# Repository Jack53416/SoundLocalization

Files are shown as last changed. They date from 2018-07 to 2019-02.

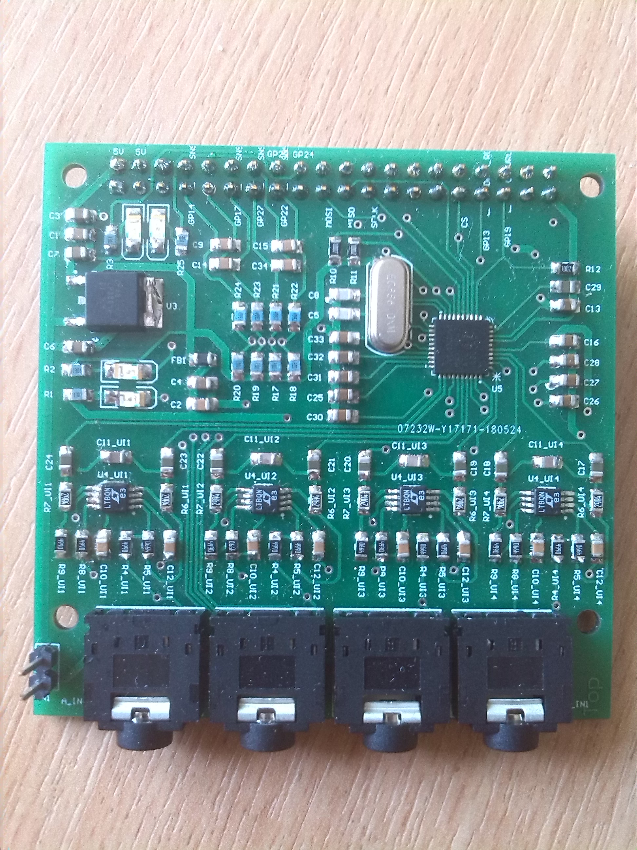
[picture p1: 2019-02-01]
docs/pictures/IMG_20180611_155353.jpg

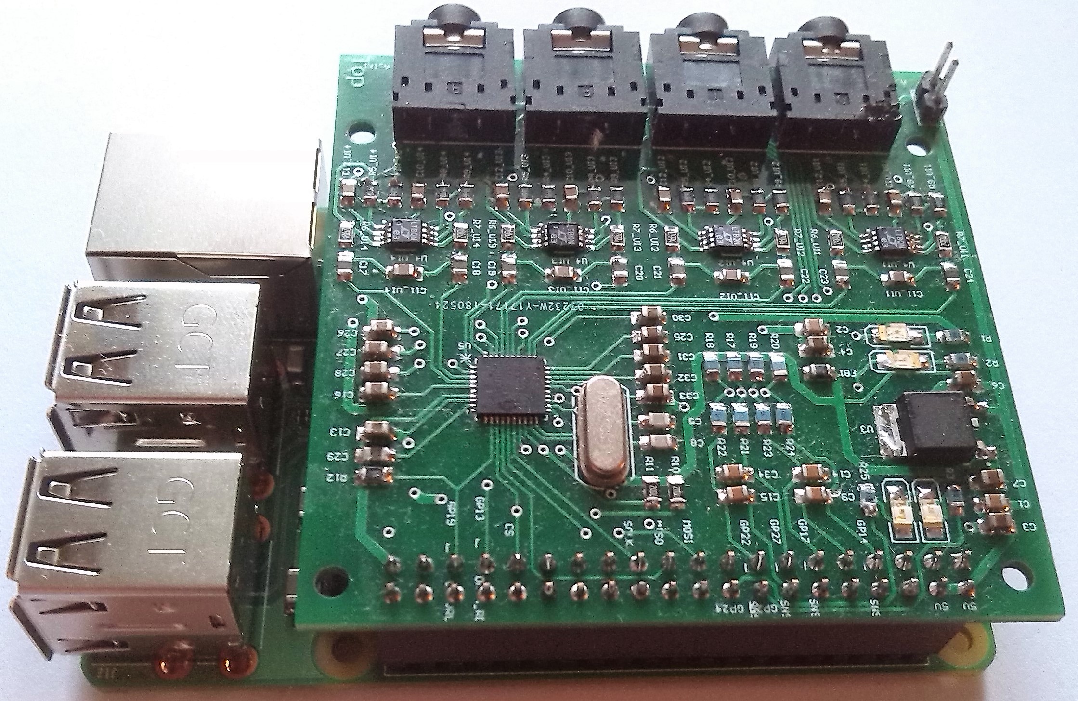
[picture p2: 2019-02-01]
docs/pictures/rPiadc.jpg

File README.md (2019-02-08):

# SoundLocalization

Project designed for localization of sound sources in 3D space. The sound source of a choice is a one emitted by a bouncing ball.

The repository consists of three separate programs:
- driver for Teensy 3.2 handling data read and tranfer from Max11043 ADC

- localizator application, that reads the raw data from USB port, then searches for bouncing ball sound. If found MLE-HLS algorithm is applied to find a src coordinates, based on known (x,y,z) positions of microphones.

- webserver and GUI client is a TypeScript app that handles websocket connections between loclaizator and browser. In a browser the GUI is displayed when connected with the server via HTTP. Its updates are done via websocket

Design documents regarding microphone array elements: ADC board and microphone boards are in /hardware_design directory. You will need Altium designer to open them.

The docs/ folder includes additionall material such as pictures and reference sources used in the thesis. Furthermore datasheets for MAX11043 and other hardware elements can be found there.

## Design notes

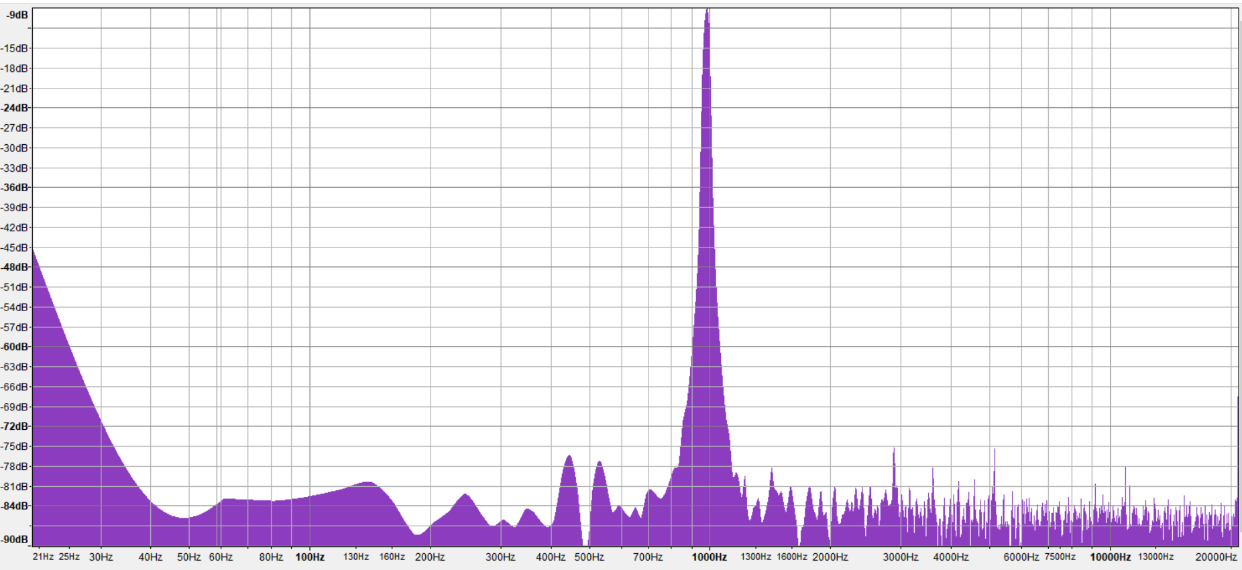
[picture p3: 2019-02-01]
docs/pictures/adc spectro, 2048, hanning.PNG

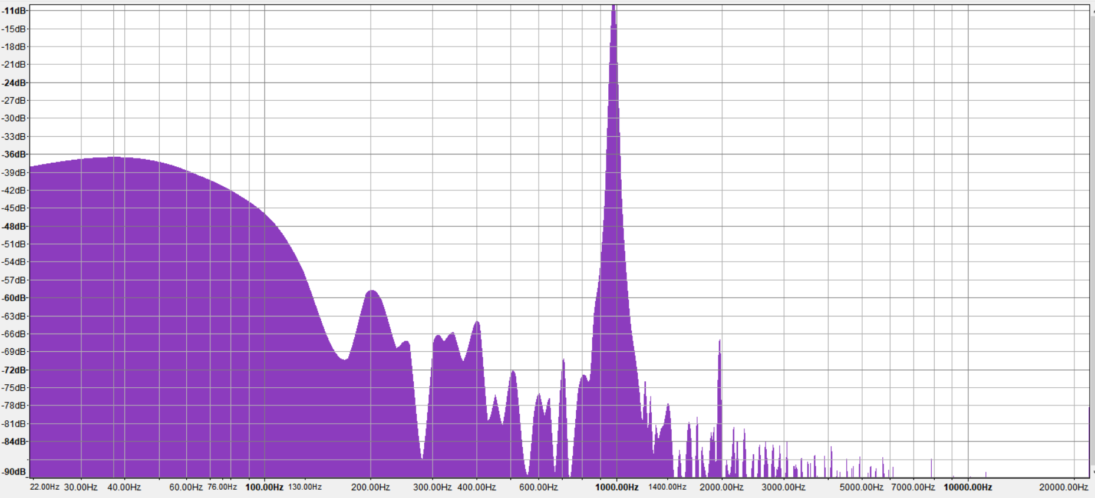
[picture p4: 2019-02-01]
docs/pictures/mic spectro 2048 hanning.PNG

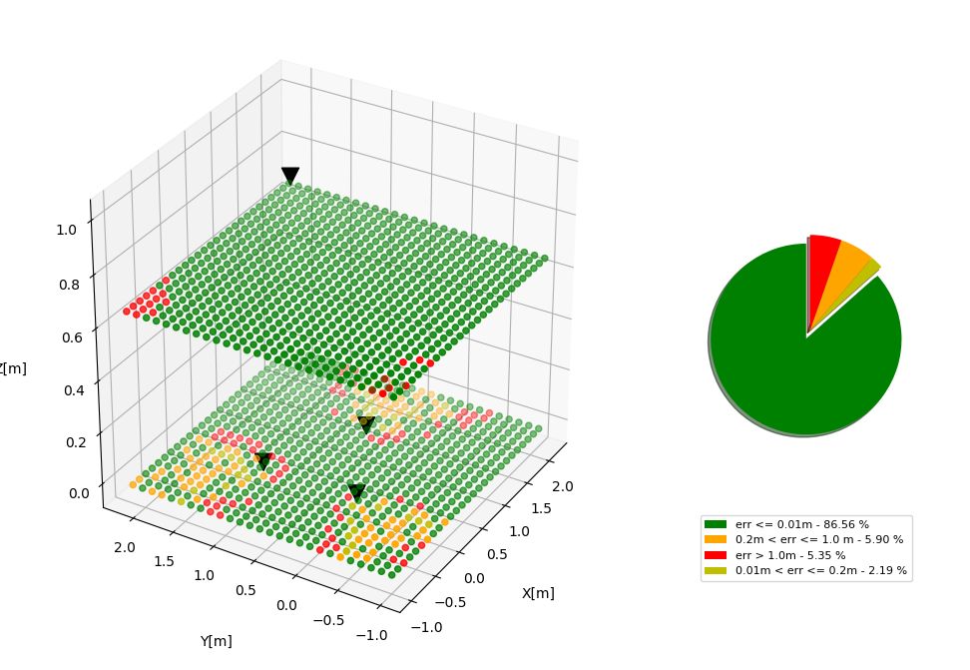
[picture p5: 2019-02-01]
docs/pictures/triangular_simulation.png

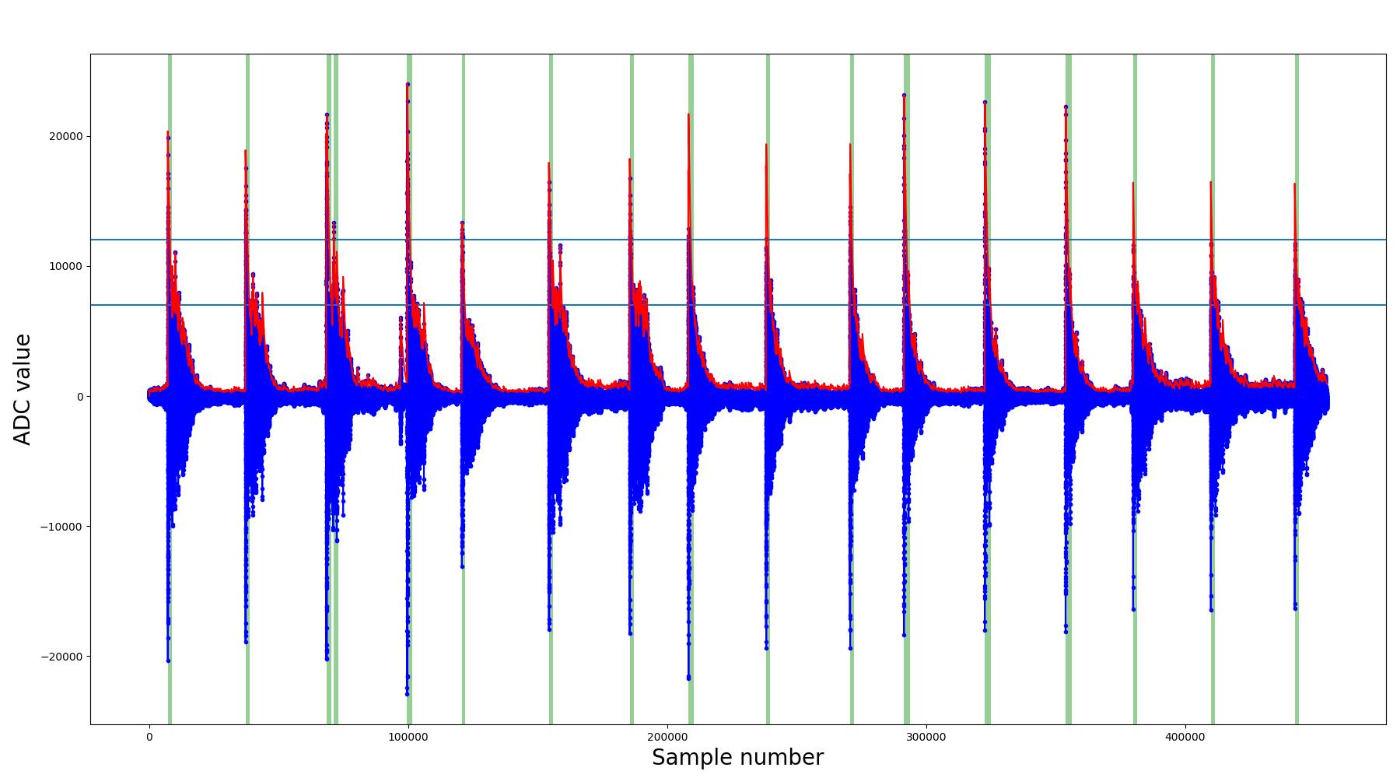
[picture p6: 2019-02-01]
docs/pictures/signal_whole.png

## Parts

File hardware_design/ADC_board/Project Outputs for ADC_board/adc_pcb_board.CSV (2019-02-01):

Bill of Material for
On 22.05.2018 at 19:26:33
Comment | Pattern | Quantity | Components
100n | CAPC2012X135N | 8 | C10_UI1, C10_UI2, C10_UI3, C10_UI4, C12_UI1, C12_UI2, C12_UI3, C12_UI4 | Capacitor SMD Cer 100nF 10% 16V X5R 0402
220 at 100MHz | FBC2012N | 1 | FB1 | Ferrite bead BLM21PG221SN1D 220 ohm at 100MHz 2A
47p | CAPC2012X135N | 4 | C11_UI1, C11_UI2, C11_UI3, C11_UI4 | Capacitor SMD Cer 39pF 1% 50V NP0 0603
approved sub OK | CAPC2012X135N | 31 | C1, C2, C3, C4, C5, C6, C7, C8, C9, C13, C14, C15, C16, C17, C18, C19, C20, C21, C22, C23, C24, C25, C26, C27, C28, C29, C30, C31, C32, C33, C34 | Capacitor SMD Cer 100nF 10% 50V X7R 0805
D Schottky | LED-0805-A | 2 | D4, D5 | Schottky Diode
Header 20X2 | HDR2X20 | 1 | P1 | Header, 20-Pin, Dual row
Jumper | HDR1X2 | 1 | W1 | Jumper Wire
LED2 | 3.2X1.6X1.1 | 4 | D1, D2, D3, D6 | Typical RED, GREEN, YELLOW, AMBER GaAs LED
LP38690DT-3.3 | TD03B_N | 1 | U3 | 1A Low Dropout CMOS Linear Regulators, 3-pin TO-252
LT1994CMS8 | LT-MS8-8_N | 4 | U4_UI1, U4_UI2, U4_UI3, U4_UI4 | Single Channel, Low Noise, Low Distortion Fully Differential Input / Output Amplifier / Driver, 70 MHz Typical GBW, 65 V/us Typical SR, 2.375 to 12.6 V, 8-Pin SOP (MS8-8), Commercial
MAX11043ATL+ | 21-0141I_T4066-5 | 1 | U5 | Imported
Phonejack3 TN | SJ1-352XN FEMALE JACK | 4 | J1, J2, J3, J4 | Jack Socket, 1/4 [6.5mm] | Thru-Hole | Vertical | 3-Conductor with Tip closed & Ring open"
Thick Film | RESC2012X70N | 43 | R1, R2, R3, R4_UI1, R4_UI2, R4_UI3, R4_UI4, R5_UI1, R5_UI2, R5_UI3, R5_UI4, R6_UI1, R6_UI2, R6_UI3, R6_UI4, R7_UI1, R7_UI2, R7_UI3, R7_UI4, R8_UI1, R8_UI2, R8_UI3, R8_UI4, R9_UI1, R9_UI2, R9_UI3, R9_UI4, R10, R11, R12, R13, R14, R15, R16, R17, R18, R19, R20, R21, R22, R23, R24, R25 | Resistor SMD chip 1.3k Ohm 0.125W 1% 0805
XTAL | Quartz Crystal HC-49USSX | 1 | Y1 | Crystal Oscillator

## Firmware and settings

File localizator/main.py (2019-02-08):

import sys
from twisted.python import log
from localizator.sensor_matrix import SensorMatrix
from localizator.connection import Connection, App

sensorMat = SensorMatrix([
    (0.0, 0.0, 0.72),
    (0.0, 1.11, 1.0),
    (1.15, 1.11, 0.72),
    (1.14, 0.0, 0.72)
], debug=True)


def __main__():
    log.startLogging(sys.stdout)
    App.onSimulate = sensorMat.simulate_wave_propagation
    App.onSettings = sensorMat.update_receiver_pos
    connection = Connection()
    connection.run()


def test():
    sensorMat.start_cont_localization(input_src="wav", filename="samples/finalTest2.wav")

#__main__()

test()

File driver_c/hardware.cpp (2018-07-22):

#include <stdio.h>
#include <stdlib.h>
#include <stdint.h>
#include "hardware.h"

#include <SPI.h>

int spiHandle = -1;
uint8_t csPin = 0;
uint8_t dataReadyPin = 0;
uint8_t convRunPin = 0;

int hardware_init(){
	return 0;
}

int spi_init(uint8_t cs, uint8_t dataReady, uint8_t convRun){
	csPin = cs;
	dataReadyPin = dataReady;
	convRunPin = convRun;
	///TO DO SPI platform init and GPIO init
  pinMode(dataReady, INPUT);
  pinMode(convRunPin, OUTPUT);
  pinMode(csPin, OUTPUT);
  //SPI.setClockDivider(SPI_CLOCK_DIV2);
  SPI.beginTransaction(SPISettings(40000000, MSBFIRST, SPI_MODE0));
  spiHandle = 0;
	return spiHandle;
}

void spi_close(){
}

void hardware_disable(){
}

void spi_write(char *data, size_t byteCount){
  SPI.transfer(data, byteCount);
}

void spi_read(char *buffer, size_t byteCount){
  for(unsigned int i = 0; i < byteCount; i++){
      buffer[i] = SPI.transfer(0x00);
    }
}

void spi_read_back(char *buffer, size_t byteCount){
  for(int i = byteCount - 1; i >= 0; i--){
    buffer[i] = SPI.transfer(0x00); 
  }  
}

void spi_xfer(char *txData, char *rxData, size_t byteCount){
  for(unsigned int i = 0; i < byteCount; i++){
      rxData[i] = SPI.transfer(txData[i]);
    }
}

void spi_cs_low(){
  digitalWrite(csPin, LOW);
}

void spi_cs_high(){
  digitalWrite(csPin, HIGH);
}

void conv_run_high(){
  digitalWrite(convRunPin, HIGH);
}

void conv_run_low(){
  digitalWrite(convRunPin, LOW);
}

void register_callback(void (*cb)()){
  attachInterrupt(digitalPinToInterrupt(dataReadyPin), cb, FALLING);
}

void remove_callback(){
  detachInterrupt(digitalPinToInterrupt(dataReadyPin));
}

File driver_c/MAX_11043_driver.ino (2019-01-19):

#include "driver.h"
#include "registers.h"
#include "hardware.h"
#include <SPI.h>

IntervalTimer statusTimer;

int counter = 0;

void setup() {
  MAX11043_STATUS adcStatus = STATUS_OK;
  SPI.begin();
  Serial.begin(2000000);
  spi_init(2,3,4);
  adcStatus = MAX11043_init(CHANNEL_A | CHANNEL_B | CHANNEL_C | CHANNEL_D, 2048, CLK_DIV_1_TO_6);
  if(adcStatus != STATUS_OK){
    pinMode(13, OUTPUT);
    signalizeError(adcStatus);
  }
  statusTimer.begin(serialStatus, 500000);
}

void loop() {
  #define SAMPLE_SIZE 4 * sizeof(int16_t)
  
  byte buff[SAMPLE_SIZE];
  bool dataReady = false;
  int16_t channelData = -1;
  
  if(digitalRead(3) == LOW && !dataReady){
      spi_cs_low();
      spi_read_back((char*)buff, SAMPLE_SIZE);
      spi_cs_high();
      dataReady = true;
  }

  if(Serial.dtr() && dataReady){
      channelData = buff[0] << 8 | buff[1];
      Serial.write(buff, SAMPLE_SIZE);
      dataReady = false;
    }
}

void timeThis(void (*f)(void), const char* test_name, unsigned int times) {
   unsigned long duration;
   float total;

   total = 0;
   duration = 0;
   for (unsigned int i = 0; i < times; i++) {
       duration = micros();
       f();
       duration = micros() - duration;
       total += duration;
   }
   
   if (times > 1) {
       total /= (float)times;
   }
   
   Serial.println("");
   Serial.print(test_name);
   Serial.print('(');
   Serial.print(times);
   Serial.print("): ");
   Serial.print(total);
   Serial.println("us");
}

void signalizeError(MAX11043_STATUS errorCode){
  while(true){
    Serial.print("ERROR: ");
    Serial.print(errorCode);
    Serial.print("\r\n");
    blinkDiode();
    delay(2000);
  }  
}

void blinkDiode(){
  static bool diodeState = false;
  if(diodeState)
    digitalWrite(13, LOW);
  else
    digitalWrite(13, HIGH);
  diodeState = !diodeState;
}

void serialStatus(){
  static bool isConverting = false;
  bool serialStatus = !Serial.rts() && Serial.dtr();
  
  if(serialStatus && !isConverting){
      MAX11043_read_samples_cont();
      isConverting = true;
  }
  else if(!serialStatus && isConverting){
      MAX11043_stop_reading_samples();
      isConverting = false;
  }  
 }

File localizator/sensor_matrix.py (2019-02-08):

import numpy as np
import serial
import struct
from bisect import bisect_left
from collections import deque
from typing import Tuple, List, NamedTuple, Sized, Iterable
import itertools
from localizator.receiver import Receiver, SliceDeck
from localizator.dft import DFT
from localizator.MLE import MLE
from localizator.math_tools import gcc_phat
from localizator.sound_detector import SoundDetector

import matplotlib.pyplot as plt
import librosa
import librosa.display


class HistoryEvent(object):
    def __init__(self, start_idx: int, end_idx: int, result: List[np.ndarray]):
        self.start_idx = start_idx
        self.end_idx = end_idx
        self.result = result

    def decrement_indexes(self, value) -> bool:
        self.start_idx -= value
        self.end_idx -= value
        return self.start_idx < 0


class DebugHistory(object):

    def __init__(self, data_chunk: int, buffer_size: int):
        self.data_buffer = SliceDeck(maxlen=buffer_size)
        self._data_chunk = data_chunk
        self._events: List[HistoryEvent] = []
        self._time_offset = 0

    def extend_data(self, data: Sized):
        if len(self.data_buffer) + len(data) > self.data_buffer.maxlen:
            self._time_offset += len(data)

        self.data_buffer.extend(data)

    def append_event(self, overall_idx: int, s_idx, e_idx: int, result: List[np.ndarray]):

        if e_idx > self._data_chunk:
            overall_idx -= 1
            s_idx -= self._data_chunk
            e_idx -= self._data_chunk

        l_bound = overall_idx * self._data_chunk + s_idx
        u_bound = overall_idx * self._data_chunk + e_idx

        self._events.append(HistoryEvent(l_bound, u_bound, result))

    def plot(self, env_history: np.ndarray = np.array([])):
            time_axis = range(self._time_offset, self._time_offset + len(self.data_buffer))
            plt.figure(figsize=(18, 10))
            plt.plot(time_axis, np.array(self.data_buffer), 'b.-')
            plt.axhline(y=12000)
            plt.axhline(y=7000)

            for event in self._events:
                if event.start_idx >= self._time_offset:
                    plt.axvspan(event.start_idx, event.end_idx, facecolor='#2ca02c', alpha=0.5)

            plt.plot(time_axis, np.array(env_history), 'r')
            plt.tight_layout(rect=[0.02, 0.03, 1, 0.95])
            plt.xlabel("Sample number", fontsize=20)
            plt.ylabel("ADC value", fontsize=20)
            plt.savefig("signal.png")
            plt.show()


class SensorMatrix(object):

    class InvalidInput(Exception):
        pass

    def __init__(self,
                 receiver_coords: List[Tuple[float, float, float]],
                 reference_rec_id: int = 0,
                 rec_buff_size: int = 4096 * 2,
                 sampling_freq: int = 41666,
                 data_chunk: int = 4096,
                 debug: bool = False):

        receivers: List[Receiver] = [Receiver(rec[0], rec[1], rec[2], buffer_size=rec_buff_size)
                                     for rec in receiver_coords]
        debug_buff_size = 120 * data_chunk
        self._sound_detector = SoundDetector(0.9993, debug_buff_size)
        self._mle_calc = MLE(receivers, src_conditions=lambda src: 0 <= src[2] < 2.0, reference_rec_id=reference_rec_id)
        self._data_chunk = 4096
        self._dft = DFT(512, sampling_freq)
        self._rec_dft_buff = np.array([])
        self._serial_settings = {
            "channelNr": 4,
            "port": '/dev/ttyACM0',
            "baud": 2000000,
            "timeout": 1,
            "resultSize_bytes": 2
        }
        self._recognition_settings = {
            "lowSpectrum": 7000,
            "highSpectrum": 12000,
            "minPart": 0.05,
            "noiseFloor": 5000
        }

        self.debug = debug

        self.debug_history = DebugHistory(data_chunk, debug_buff_size)

    def start_cont_localization(self, input_src: str = "serial", filename="input.wav"):
        byte_count = self._serial_settings["channelNr"] * self._data_chunk * self._serial_settings["resultSize_bytes"]
        Receiver.isSimulation = False

        if input_src == "wav":
            import wave

            with wave.open(filename, "rb") as wav:
                self._dft.sampling_rate = wav.getframerate()
                self._serial_settings["channelNr"] = wav.getnchannels()
                length = wav.getnframes() // self._data_chunk

                for idx in range(0, length):
                    input_bytes = wav.readframes(self._data_chunk)
                    self.localize(input_bytes, idx)

                if self.debug:
                    self.debug_history.plot(self._sound_detector.env_history)
        else:
            with serial.Serial(self._serial_settings["port"],
                               self._serial_settings["baud"],
                               timeout=self._serial_settings["timeout"]) as ser:
                while ser.is_open:
                    input_bytes = ser.read(byte_count)
                    self.localize(input_bytes)

    def localize(self, raw_data: bytes, idx: int = 0):
        """Performs the whole localization process: check for searched signal, and if it is found calculate the
        src position, returns true if it was detected and false otherwise(for statistics)"""
        byte_len = len(raw_data)
        frames: List[int] = struct.unpack("{}h".format(byte_len // self._serial_settings["resultSize_bytes"]),
                                          raw_data)
        recs = self._mle_calc.receivers
        energy = []

        # Split data into separate channels
        for ch_id in range(0, self._serial_settings["channelNr"]):
            ch_data = np.array(frames[ch_id::self._serial_settings["channelNr"]], dtype=np.float32)
            energy.append(sum(map(lambda x: x * x, ch_data)))
            recs[ch_id].data_buffer.extend(ch_data)

        # claculate energy of all channels na choose the strongest
        strongest_idx: int = np.argmax(energy)

        if self.debug:
            self.debug_history.extend_data(recs[strongest_idx].data_buffer[self._data_chunk::])

        signal_buffer = recs[strongest_idx].data_buffer

        self._sound_detector.detect_sound(signal_buffer, 12000, 7000, data_offset=self._data_chunk)

        while len(self._sound_detector.events) > 0:
            l_idx, h_idx, s_mic = self._sound_detector.events.pop()

            is_event = self.is_event_detected(signal_buffer[l_idx: h_idx])

            if is_event:
                # find TdoA
                self.calculate_tdoa(l_idx, h_idx)
                # calculate src
                res = self.estimate_src_position()
                print("calculation result:{}".format(res))
                self.debug_history.append_event(idx, l_idx, h_idx, res)
                # send to server
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

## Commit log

2018-04-08 Add test class to asses accurracy and fix minor problems
    -Fix issue with non-repetative source point calculations
    -Remove legacy code, clean up
    [MLE.py]
2018-07-01 Add MAX11043 driver template
2018-07-01 Attach hardware spi library to project
2018-07-02 Refactor ADC_DRIVER into python package
    -Refactor code into package
    -Add prototype for adc channel reading
2018-07-03 Rewrite adc driver in C for optimization
2018-07-09 Add channel register config to python driver
2018-07-13 Refactor the driver's code, make it more like a library
2018-07-14 Improve performace by using only sizes of power of 2
2018-07-22 Rewrite the code for Teensy 3.2 development board
    -Rename spi module to hardware
    -Delete wavWriter module as its done in python now
2018-10-05 Add module responsible for socket connection on the worker side
2018-11-30 Fix bugs in the gcc interopolation, setup new test for recognition
    [math_tools.py]
2018-12-03 Correctly assign boolean variable if the mic is reference
    [MLE.py]
2018-12-03 Replace deque with simple array as a data buffer
    [receiver.py]
2018-12-18 Update driver code, add sampling on trigger
2019-01-04 Rework bunce detection and TDoA calculation process
    [sensor_matrix.py]
2019-01-04 Implement various bug fixes
    [MLE.py, dft.py, main.py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]
2019-01-16 Rework the HLS function, add custom user conditions to determine correct root
    [MLE.py]
2019-01-22 Rework the simulation module, provide better configuration
    [MLE.py, sensor_matrix.py]
2019-02-01 Fix formatting error, change sound speed in the air constant
    [MLE.py, receiver.py]
2019-02-01 Remove old python driver implementation
2019-02-01 Reorganize audio samples
2019-02-01 Include hardware design projects for ADC and microphone boards
    [ADC_board.PrjPcb, ADC_connections.SchDoc, InputDriver.SchDoc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]
2019-02-08 Correct bound checking errors
    [MLE.py, dft.py, main.py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]
2019-02-08 Reorganize samples
